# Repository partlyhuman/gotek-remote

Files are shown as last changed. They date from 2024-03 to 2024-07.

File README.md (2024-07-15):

# Gotek Floppy Emulator Remote Interface

This is a device that relocates the USB, screen, and dial of a Gotek floppy drive emulator (running [FlashFloppy](https://github.com/keirf/flashfloppy)) to a standalone unit you can build yourself. It solves the problem of not having easy access to the drive, for example if your computer's front panel doesn't have a cutout for it. The remote connects to the main unit via a flat flex cable (FFC) which can be threaded through the narrowest of cracks in a desktop chassis, giving you the freedom to place it wherever you prefer.

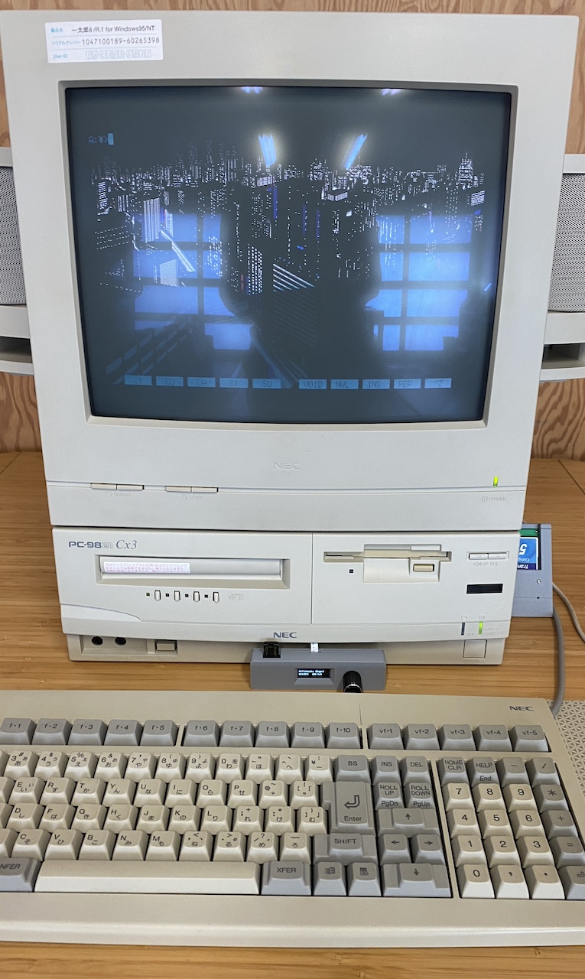
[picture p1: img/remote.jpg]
The remote being used with a PC-9821


https://github.com/user-attachments/assets/1192d630-0beb-47c9-abd5-1f5b6c1d0ba6

## Building one

There are two (small) PCBs: One goes inside the Gotek, and the other forms the remote, along with a 3d printed case.

You'll need:

* A Gotek drive with [FlashFloppy](https://github.com/keirf/flashfloppy) installed
* A rotary encoder and 128x32 0.9" OLED screen recommended by [Hardware Mods](https://github.com/keirf/flashfloppy/wiki/Hardware-Mods)
* A USB-A through-hole female connector
* A 10-pin, 0.5mm pitch, straight-through FFC of the desired length (shorter is better)
* Two 10-pin, 0.5mm pitch, SMD FFC connectors
* An electrolytic capacitor for the USB connector, 10uF?
* Some M2 screws
* The two PCBs, fab-ready gerbers are available for the [breakout](pcb/production/gotek-breakout.zip) and [remote](pcb/production/gotek-remote.zip)
* A 3d printed case, print-ready STLs are available for the [top](3dp/Gotek%20Remote_Gotek%20Remote%20Dock%20v20_Case%20Top.stl) and [bottom](3dp/Gotek%20Remote_Gotek%20Remote%20Dock%20v20_Case%20Bottom.stl)
* Optional, a 2x2 right angle female 2.54mm pitch header pin socket
* Optional, two sticky-backed PCB standoffs 

Assembly:

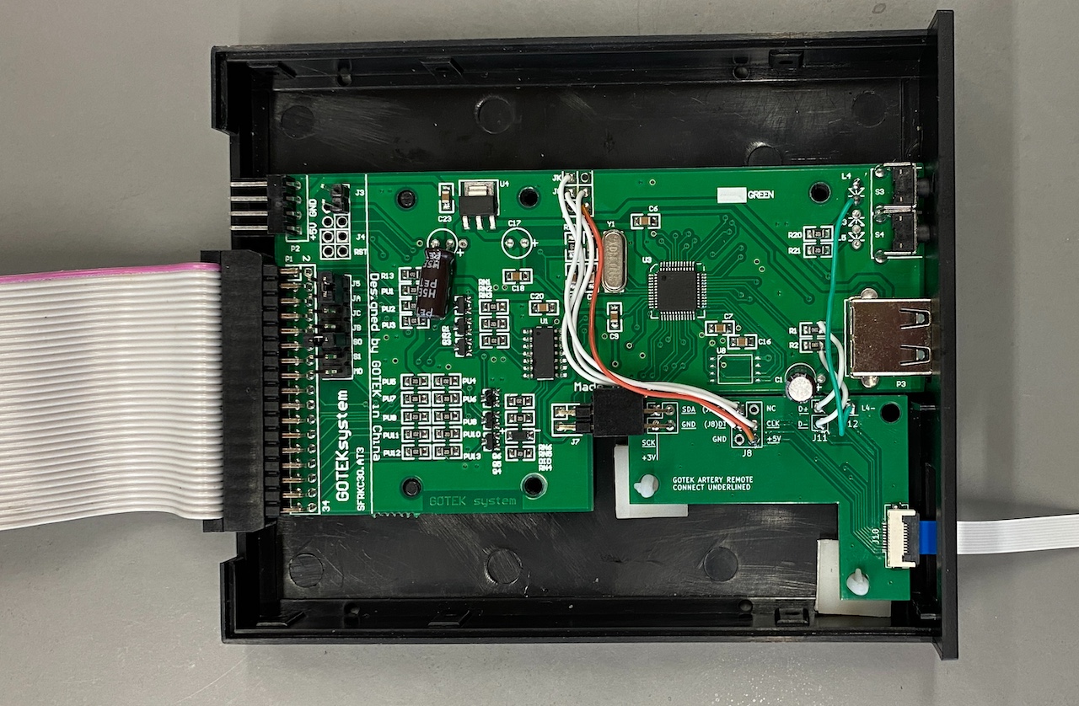
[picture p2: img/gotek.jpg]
The breakout, connected


Connect the underlined connections. J8 mirrors the headers mid-board in these revisions of the Gotek, in the same positions, only the underlined connections are needed. J11 goes to the right side of R1 and R2 (in the same order). Make an effort to have these USB jumper wires the same length, and as short as possible. Optionally, J12 goes to the bottom side of the L4 activity LED (replacing the LED). The right-angle connector will make the board slip into place.

Connect the FFC, feed it through the hole left by the screen and out the front of your PC. Hook up the floppy side of things.

When assembling the remote, you'll probably have to desolder the angle pins of the rotary encoder and solder in straight ones. For both the rotary encoder and the OLED screen, the boards will be connected on the right side, so place a spacer on the left side to match height for better support - I use sticky tack. Trim the excess off the header pins for a flush fit.

Assemble the remote in this order:

1. Front side of the case
2. The remote PCB
3. Attach the FFC now before closing the case
4. Rear side of the case, screwing all the layers together
5. Push on rotary shaft cap

I use these options in [ff.cfg](https://github.com/keirf/flashfloppy/wiki/FF.CFG-Configuration-File#options):

* `display-type = oled-128x32-rotate-slow`
* `rotary = half`

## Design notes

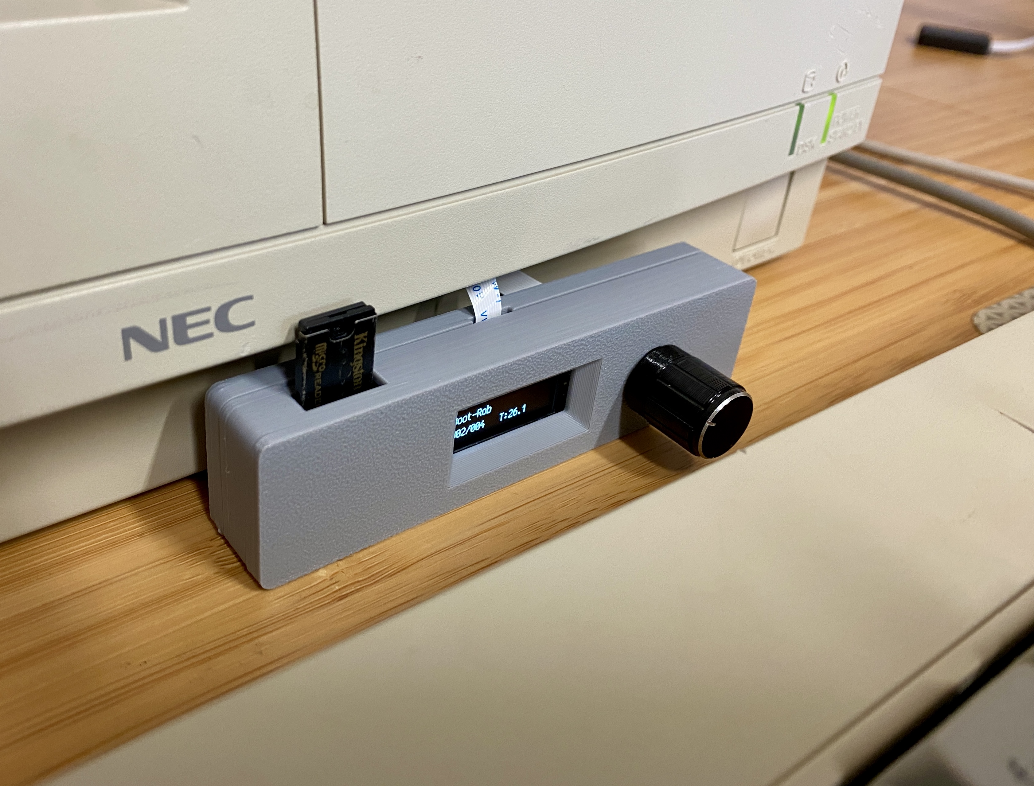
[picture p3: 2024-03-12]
img/remote-closeup-standing.jpg

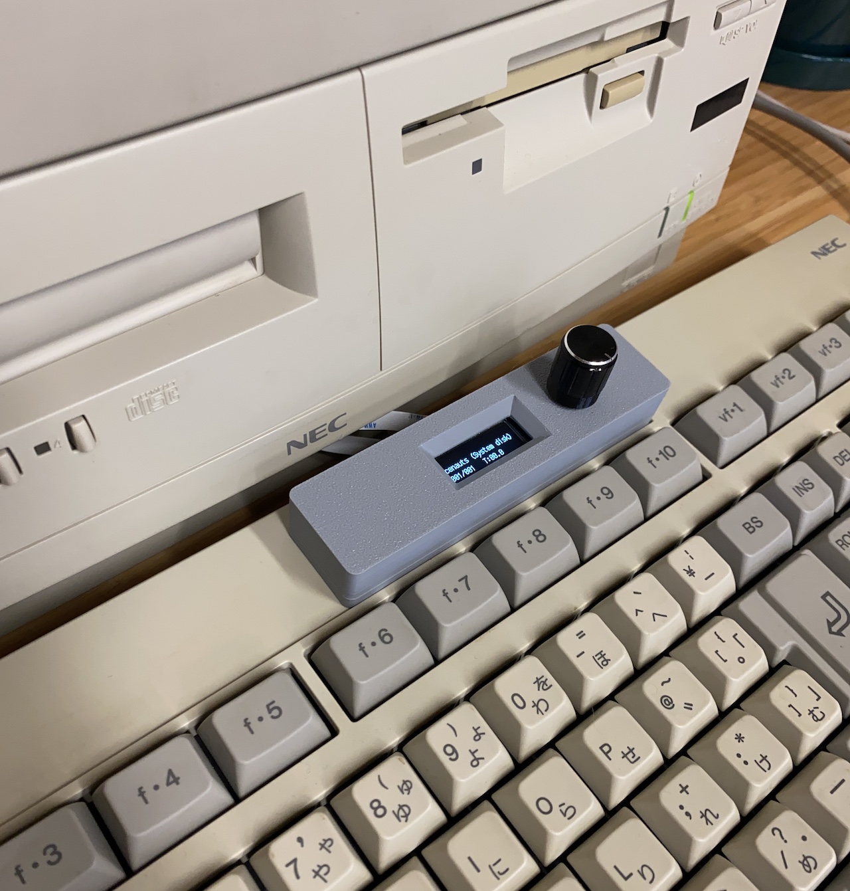
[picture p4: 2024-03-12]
img/remote-keyboard.jpg

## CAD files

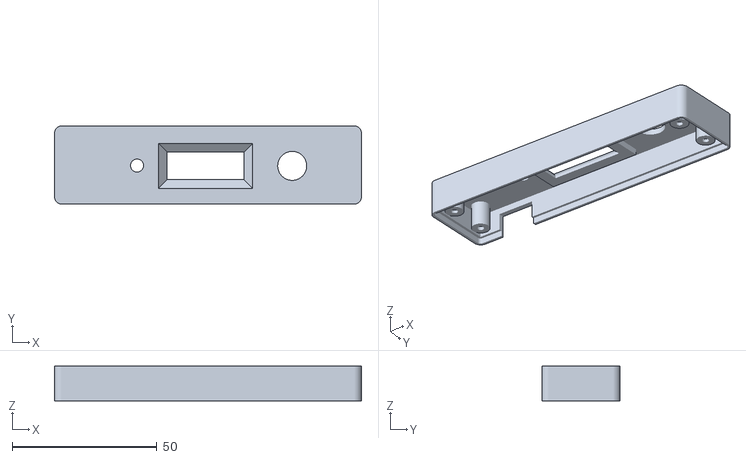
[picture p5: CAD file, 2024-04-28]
3dp/Case_Gotek Remote Dock v25_Case Top.stl
106.0 x 27.0 x 12.0

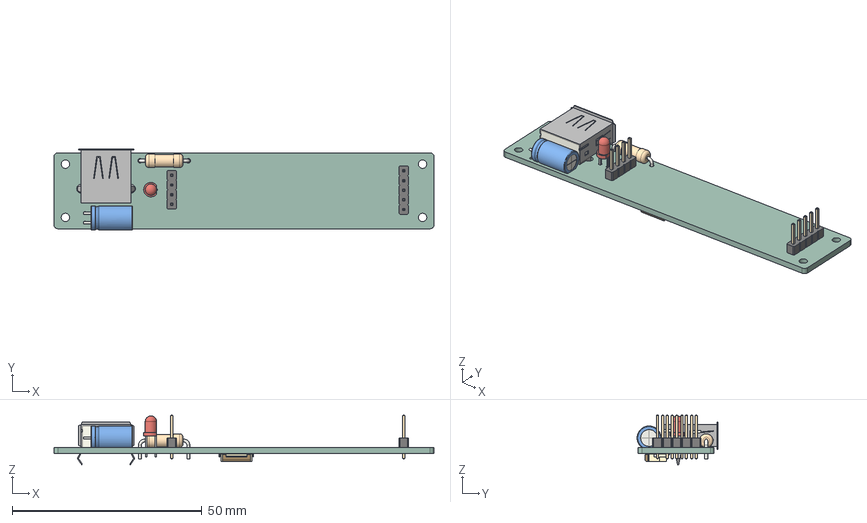
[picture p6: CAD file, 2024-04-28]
pcb/gotek-breakout.step
100.0 x 21.3 x 13.1 mm
USB_A_TE_292303-7_Horizontal
LED_D3.0mm
PinHeader_1x05_P254mm_Vertical
C_Radial_D63mm_H110mm_P250mm
PinHeader_1x04_P254mm_Vertical
R_Axial_DIN0411_L99mm_D36mm_P1270mm_Horizontal
Hirose_FH12_xxS_0_5SH_Parametric_v0_1
_autosave-gotek-breakout_PCB

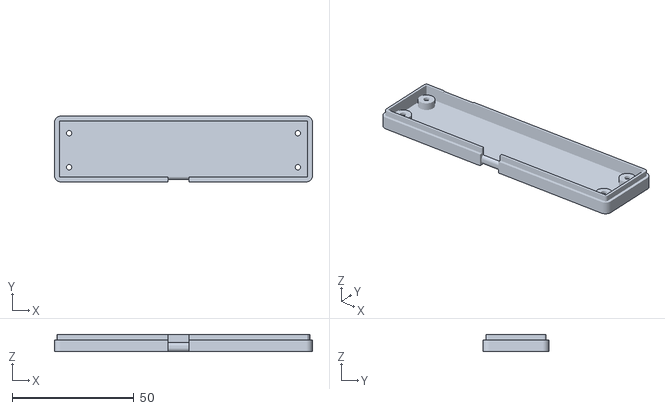
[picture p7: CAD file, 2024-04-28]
3dp/Case_Gotek Remote Dock v25_Case Bottom.stl
106.0 x 27.0 x 7.00

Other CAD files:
3dp/Gotek Remote Dock v20.f3d

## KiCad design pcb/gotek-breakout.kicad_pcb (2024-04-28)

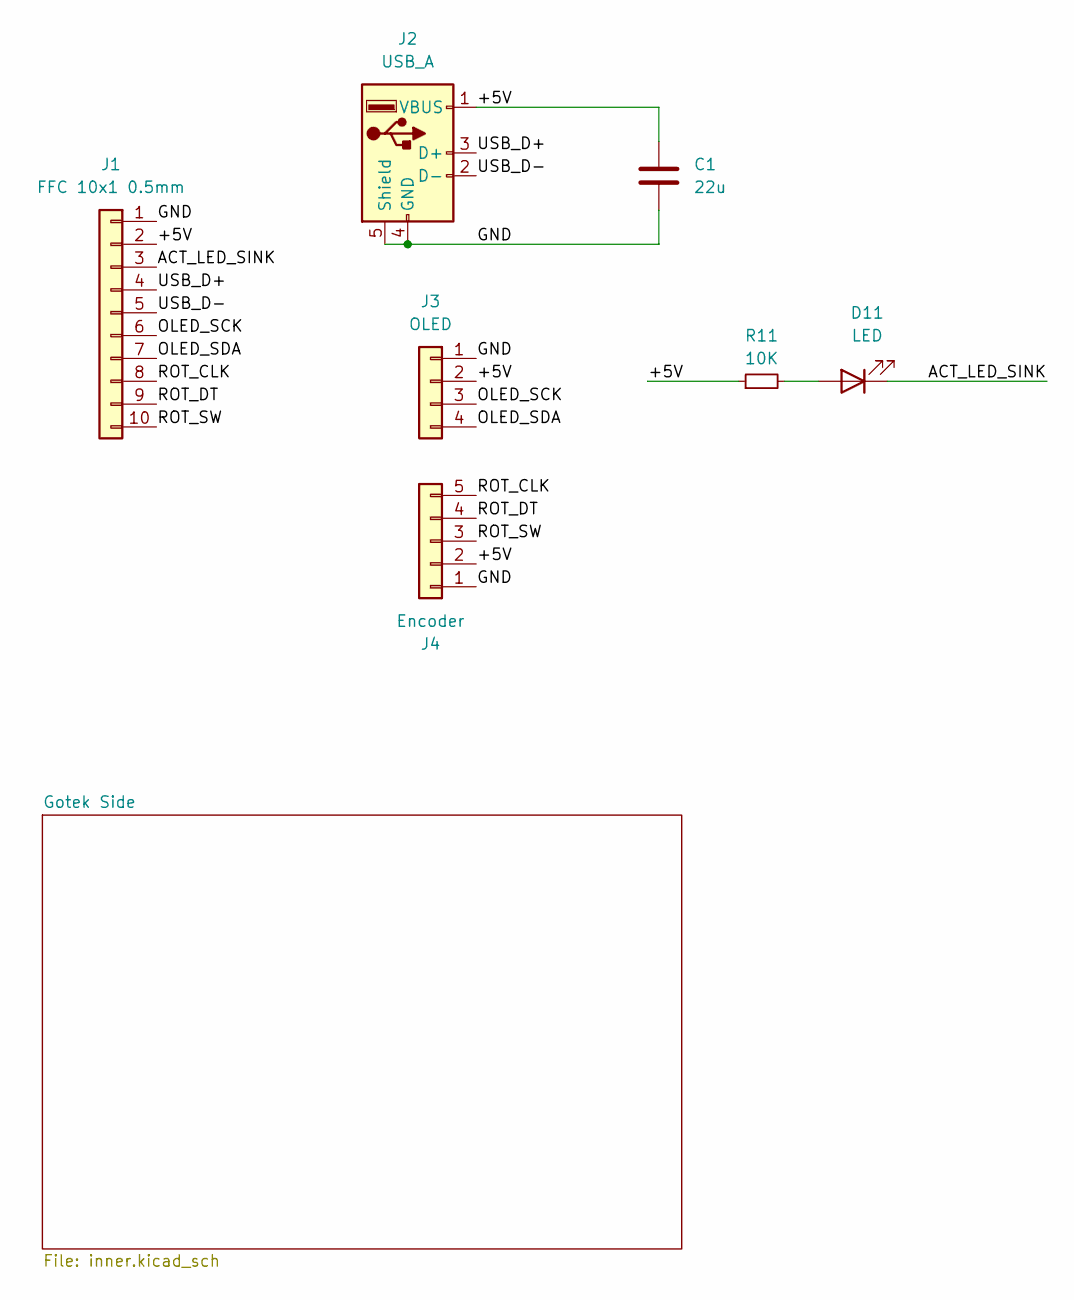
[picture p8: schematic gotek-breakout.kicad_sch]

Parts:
C1: 22u; CP_Radial_D5.0mm_P2.50mm
D11: LED; LED_D3.0mm
J1: FFC 10x1 0.5mm; Molex_54548-1071_1x10-1MP_P0.5mm_Horizontal
J2: USB_A; USB_A_Molex_67643_Horizontal
J3: OLED; PinHeader_1x04_P2.54mm_Vertical
J4: Encoder; PinHeader_1x05_P2.54mm_Vertical
R11: 10K; R_Axial_DIN0411_L9.9mm_D3.6mm_P12.70mm_Horizontal

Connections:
/+5V: C1.1, J1.2, J2.1 (VBUS), J3.2, J4.2, R11.1
/ACT_LED_SINK: D11.1 (K), J1.3
/GND: C1.2, J1.1, J2.4 (GND), J2.5 (Shield), J3.1, J4.1
/OLED_SCK: J1.6, J3.3
/OLED_SDA: J1.7, J3.4
/ROT_CLK: J1.8, J4.5
/ROT_DT: J1.9, J4.4
/ROT_SW: J1.10, J4.3
/USB_D+: J1.4, J2.3 (D+)
/USB_D-: J1.5, J2.2 (D-)
unnamed: D11.2 (A), R11.2

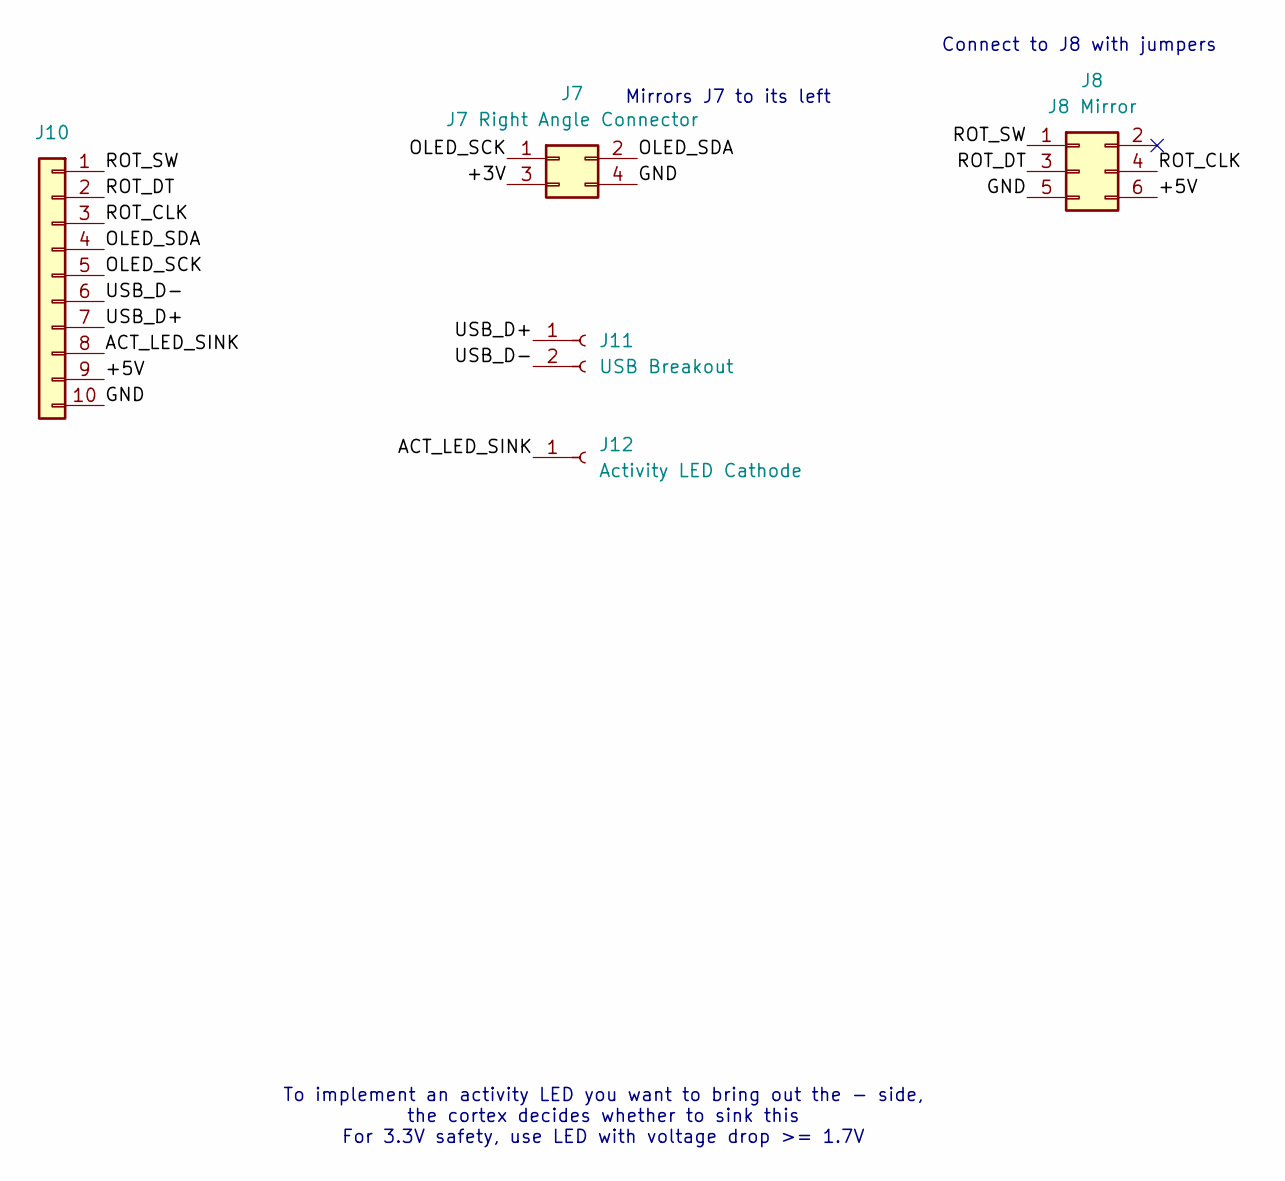
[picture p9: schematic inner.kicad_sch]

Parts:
J7: J7 Right Angle Connector; PinHeader_2x02_P2.54mm_Vertical
J8: J8 Mirror; PinHeader_2x03_P2.54mm_Vertical
J10: FFC 10x1 0.5mm; Molex_54548-1071_1x10-1MP_P0.5mm_Horizontal
J11: USB Breakout; PinHeader_1x02_P2.54mm_Vertical
J12: Activity LED Cathode; PinHeader_1x01_P2.54mm_Vertical

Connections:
/Gotek Side/+3V: J7.3
/Gotek Side/+5V: J8.6, J10.9
/Gotek Side/ACT_LED_SINK: J10.8, J12.1
/Gotek Side/GND: J7.4, J8.5, J10.10
/Gotek Side/OLED_SCK: J7.1, J10.5
/Gotek Side/OLED_SDA: J7.2, J10.4
/Gotek Side/ROT_CLK: J8.4, J10.3
/Gotek Side/ROT_DT: J8.3, J10.2
/Gotek Side/ROT_SW: J8.1, J10.1
/Gotek Side/USB_D+: J10.7, J11.1
/Gotek Side/USB_D-: J10.6, J11.2

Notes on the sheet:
Connect to J8 with jumpers
Mirrors J7 to its left
To implement an activity LED you want to bring out the - side, the cortex decides whether to sink this For 3.3V safety, use LED with voltage drop >= 1.7V

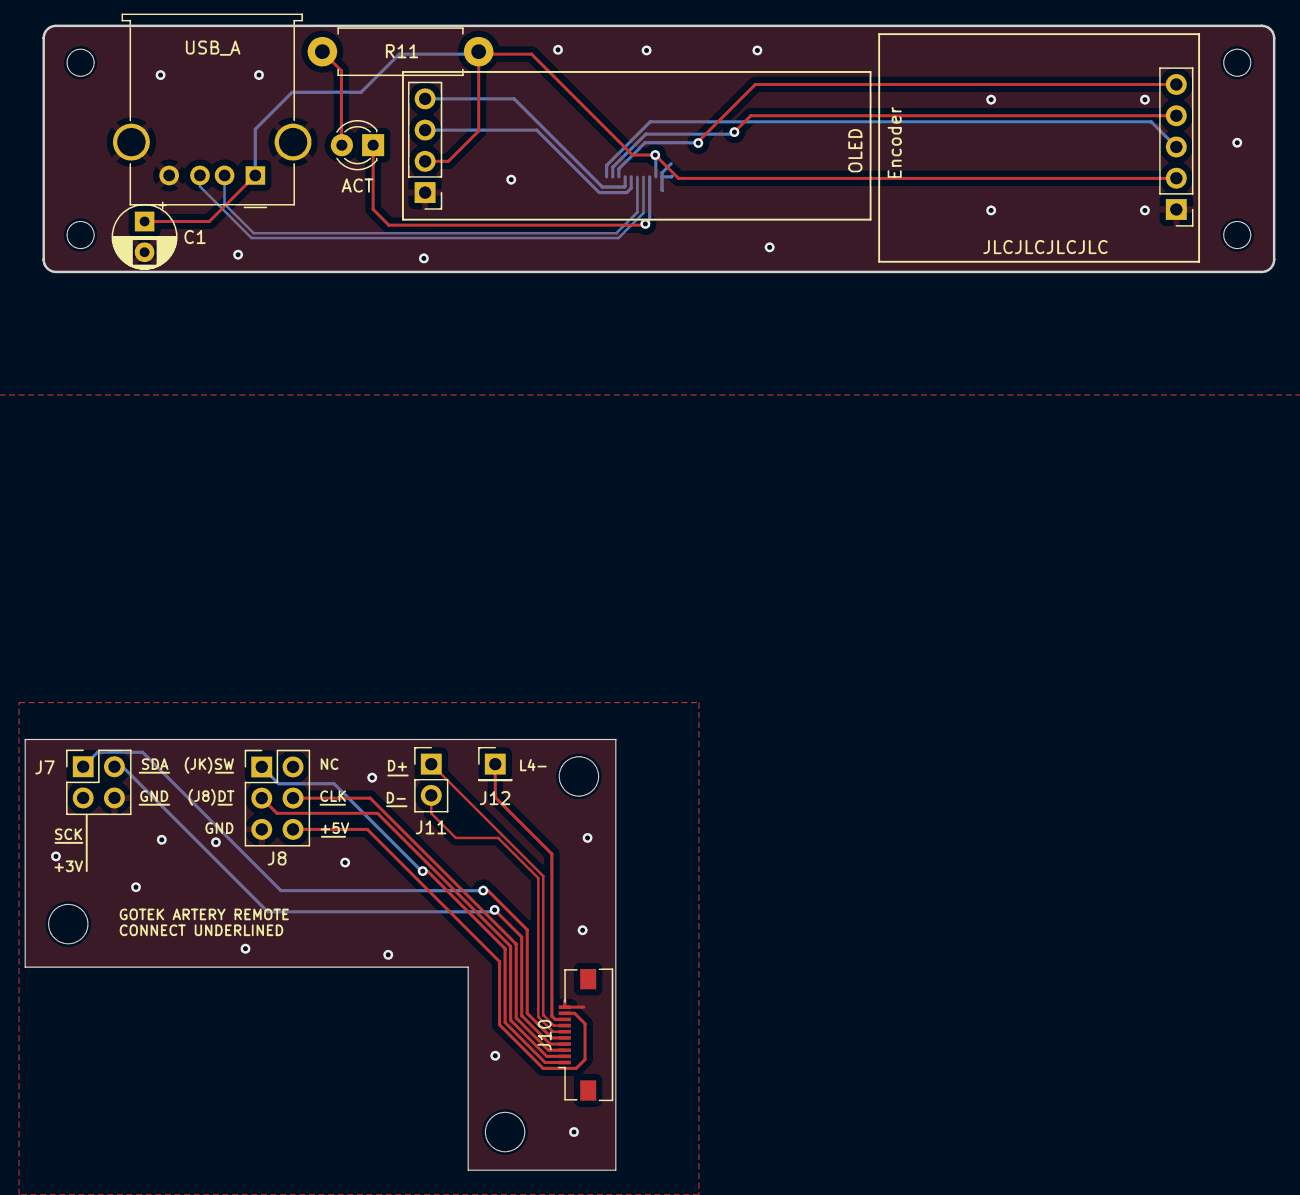
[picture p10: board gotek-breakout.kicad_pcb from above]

Board: 2 copper layers, 101.5 x 93.0 mm, 19 parts (1 on the bottom side), 21 nets.

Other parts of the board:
H1, H2, H3, H4: MountingHole_2.2mm_M2
H5, H6, H7: MountingHole_3.2mm_M3

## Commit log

2024-03-12 Make room for mounting
    [gotek-breakout.kicad_pcb, gotek-breakout.kicad_sch]
2024-03-12 Add adapter piece, need to work out mounting
    [gotek-breakout.kicad_pcb, inner.kicad_sch]
2024-03-12 Breakout board only for newer goteks
    [gotek-breakout.kicad_pcb, gotek-breakout.kicad_sch, inner.kicad_sch]
2024-03-12 add gerbers
    [gotek-breakout-B_Cu.gbr, gotek-breakout-B_Mask.gbr, gotek-breakout-B_Paste.gbr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]
2024-03-12 Adds notes
    [gotek-breakout.kicad_pcb]
2024-03-12 Match D+/D- positions better
    [gotek-breakout-B_Cu.gbr, gotek-breakout-B_Mask.gbr, gotek-breakout-B_Paste.gbr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]
2024-03-12 M2 mounting holes to match 3d print
    [gotek-breakout.kicad_pcb]
2024-03-12 Add mounting to breakout, update silk
    [gotek-breakout.kicad_pcb]
2024-03-12 Add 3d prints
    [Gotek Remote Dock v20.f3d, Gotek Remote_Gotek Remote Dock v20_Case Bottom.stl, Gotek Remote_Gotek Remote Dock v20_Case Top.stl]
2024-04-02 Revision 2
    [Gotek Remote Dock Bottom.stl, Gotek Remote Dock Top.stl, gotek-breakout.kicad_pcb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]
2024-04-03 Move FFC up
    [gotek-breakout.kicad_pcb]
2024-04-28 Tweaks for rev2
    [Gotek Remote Dock Bottom.stl, Gotek Remote Dock Top.stl, Gotek Remote Dock v23_Gotek Remote Dock v23_Case_1_Case Bottom.stl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]
2024-04-28 Nudging items on PCB for rev3
    [gotek-breakout.kicad_pcb]
2024-04-28 Updating remote gerbers
2024-04-28 Rev3 print updates
    [Case_Gotek Remote Dock v25_Case Bottom.stl, Case_Gotek Remote Dock v25_Case Top.stl, Gotek Remote Dock v23_Gotek Remote Dock v23_Case_1_Case Bottom.stl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]
